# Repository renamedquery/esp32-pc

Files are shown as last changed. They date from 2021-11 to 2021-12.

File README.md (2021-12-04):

# esp32-pc

### This repo is currently a work in progress. I am currently working on the ESP32's command line.

https://user-images.githubusercontent.com/38505228/144671347-8b8e3e65-b26e-4b90-b4b4-f55994bb42a4.mp4

*Yes, it does run Bad Apple! (Make sure to run `net stop` before using `readimgseq`). A some recent updates have sped up the playback speed monumentally, and the device is now capable of ~16fps playback!*



*Currently, the master device will now allow up to 8 slave devices to sync to it over WiFi. It can also read from an SD card filesystem.*



*One of the latest updates included the ability to take screenshots. The screenshot algorithm will be improved later to use run length encoding, which should speed it up significantly.*



*I call it, "The Signal Integrity House of Horrors".*

### Specs:

- 520KB RAM
- 448KB ROM
- 240MHz processor clock speed
- 3 bit VGA colors (RGB)
- 640x350 output resolution
- 6 physical ESP32 devices

### Parts:

- 6x ESP32-S2 Dev Kit
- 1x Digital PmodSD

### Commands:

- fbmem
- fbinfo
- hwinfo
- lsdev
- net <command_args>
- df
- sd <command_args>
- mkdir <absolute_path>
- ls
- touch <absolute_path>
- cd <absolute_path>
- readimgseq <absolute_path>
- cls
- screenshot <absolute_path>

*Use the `help` command to list all of the commands and their usage. You can comment out text by writing `nop <string>`.*

### Why am I doing this?

I have quite a bit of experience programming on high end desktop computers, and thought that it would be useful to learn how to program on a system with much tighter tolerances and lower specs.

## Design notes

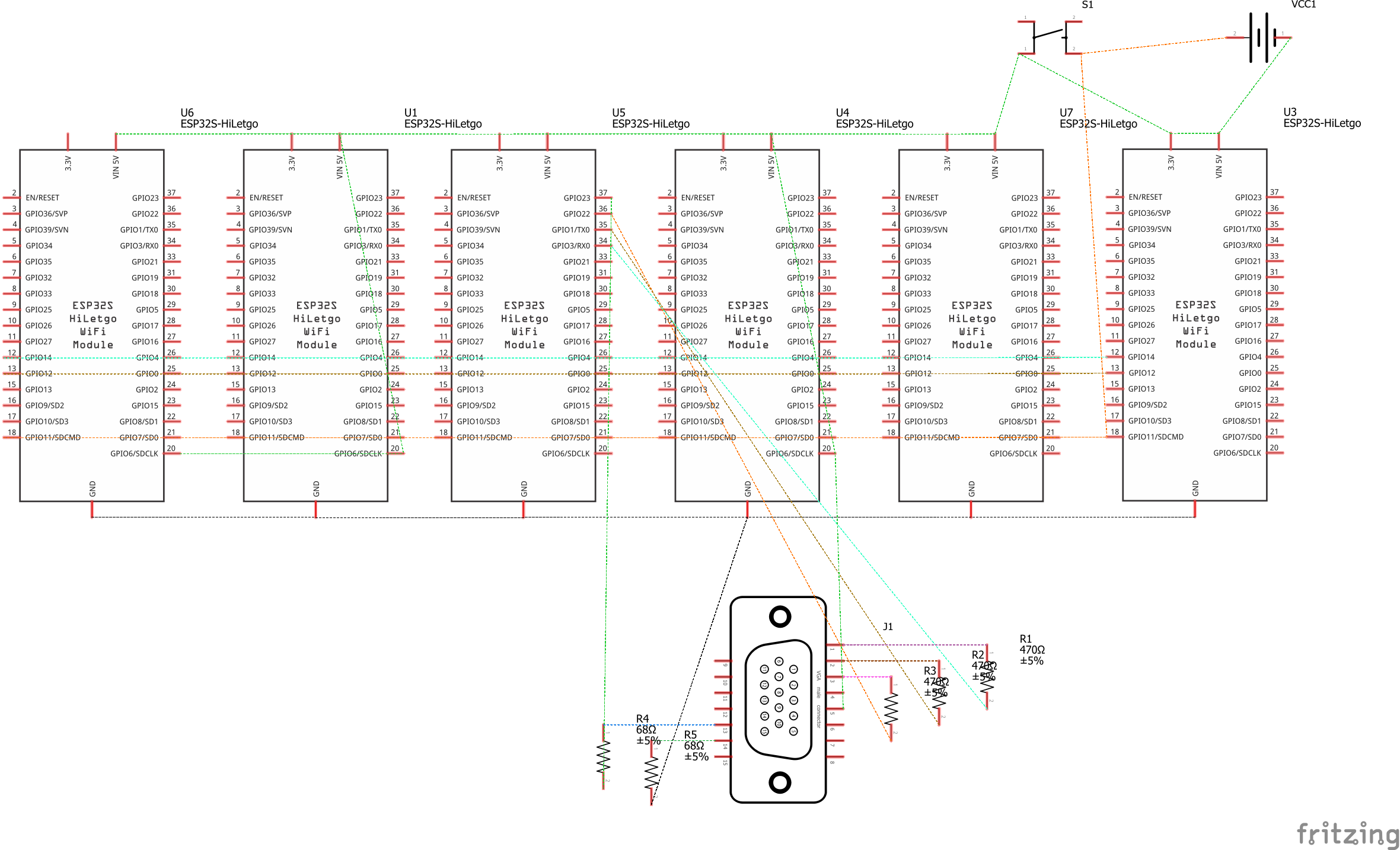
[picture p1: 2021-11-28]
schematics/esp32-computer-mockup-1_schem.png

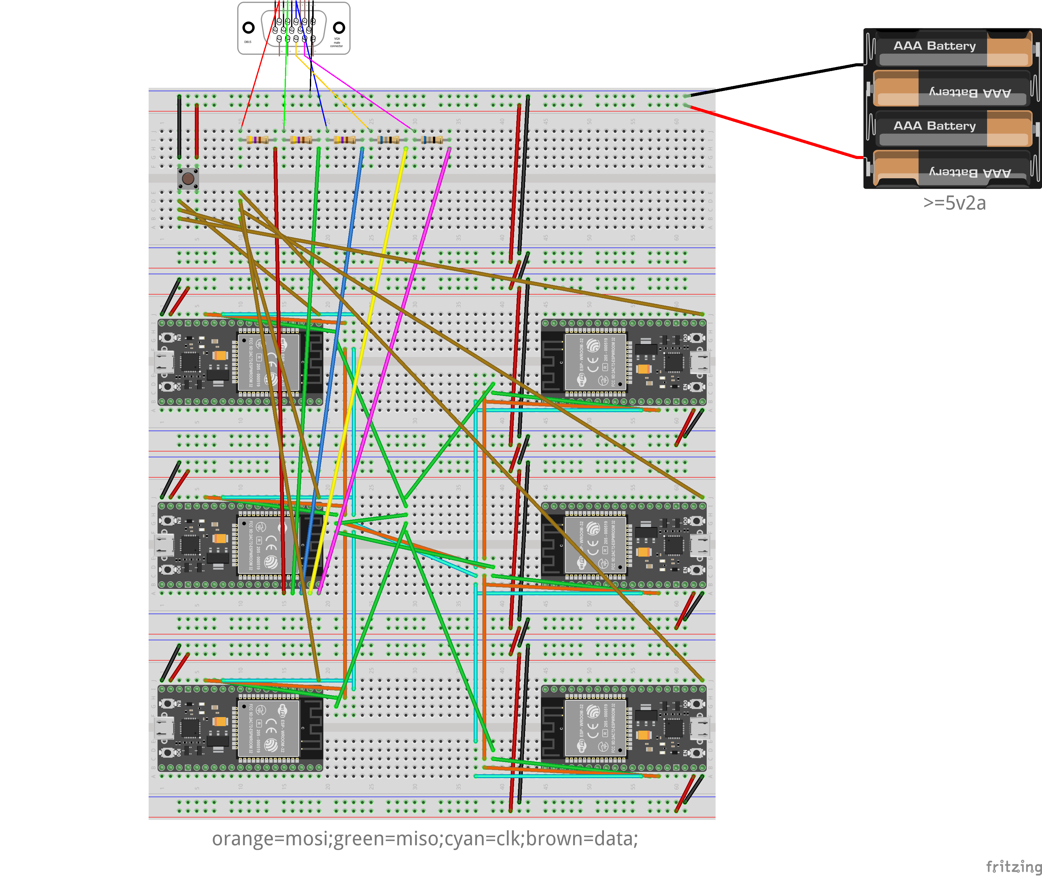
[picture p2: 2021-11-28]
schematics/esp32-computer-mockup-1_bb.png

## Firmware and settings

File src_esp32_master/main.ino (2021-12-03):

#define CONFIG_IDF_TARGET_ESP32 1

#include "cli.hpp"

void setup() {

    spi = new SPIClass(VSPI);
    spi->begin(SD_SCLK, SD_MISO, SD_MOSI, SD_SS);
    spi->setFrequency((uint32_t)(get_clock_speed_cpu_mhz()) * 1000 * 1000); // might be unstable at 240Mhz?

    WiFi.mode(WIFI_AP);
    bool softap_start_status = WiFi.softAP(WIFI_NAME, WIFI_PASSWORD, 1, 0, AP_MAX_CONNECTIONS);

    Serial.begin(9600);

    bool sd_start_status = SD.begin(SD_SS, *spi);

    vga.init(vga.MODE640x350, PIN_R, PIN_G, PIN_B, PIN_HSYNC, PIN_VSYNC);
    vga.setFont(CodePage437_9x16);
    vga.setTextColor(vga.RGB(255, 255, 255), vga.RGB(0, 0, 0));
    vga.setFrameBufferCount(2);
    vga.clear();

    char pin_info[MAX_CLI_OUTPUT_LENGTH_PER_LINE] = "";
    sprintf(pin_info, "PIN_R=%d\nPIN_G=%d\nPIN_B=%d\nPIN_HSYNC=%d\nPIN_VSYNC=%d", PIN_R, PIN_G, PIN_B, PIN_HSYNC, PIN_VSYNC);

    char clock_speed[MAX_CLI_OUTPUT_LENGTH_PER_LINE] = "";
    sprintf(clock_speed, "%dMHz CLOCK SPEED", get_clock_speed_cpu_mhz());

    char softap_start_info[MAX_CLI_OUTPUT_LENGTH_PER_LINE] = "";
    sprintf(softap_start_info, "SOFTAP STATUS %d", (byte)softap_start_status);

    char sd_start_info[MAX_CLI_OUTPUT_LENGTH_PER_LINE] = "";
    sprintf(sd_start_info, "SD STATUS %d", (byte)sd_start_status);

    pinMode(SLAVE_RESET_PIN, OUTPUT);
    digitalWrite(SLAVE_RESET_PIN, HIGH);

    vga.println("ESP-32S DEVELOPMENT BOARD");
    vga.println("520KB RAM BUILT IN/0KB EXTERNAL");
    vga.println(clock_speed);
    vga.println("640X350 PIXELS TOTAL");
    vga.println("3 BIT VGA");
    vga.println(softap_start_info);
    vga.println(pin_info);
    vga.println(sd_start_info);

    vga.println("USING ESP32LIB VGA DRIVER WRITTEN BY BITLUNI");
    vga.println("MAIN PROGRAM WRITTEN BY KATZNBOYZ");
    vga.print("REPORT ISSUES TO ");
    vga.setTextColor(vga.RGB(0, 0, 255), vga.RGB(0, 0, 0));
    vga.println("https://github.com/katznboyz1/esp32-pc");
    vga.setTextColor(vga.RGB(255, 255, 255), vga.RGB(0, 0, 0));

    vga.setTextColor(vga.RGB(255, 0, 0), vga.RGB(0, 0, 0));
    vga.println("RED COLOR TEST");
    vga.setTextColor(vga.RGB(0, 255, 0), vga.RGB(0, 0, 0));
    vga.println("GREEN COLOR TEST");
    vga.setTextColor(vga.RGB(0, 0, 255), vga.RGB(0, 0, 0));
    vga.println("BLUE COLOR TEST");
    vga.setTextColor(vga.RGB(255, 255, 255), vga.RGB(0, 0, 0));

    unsigned long boot_to_current_time = (millis() - boot_start_time);
    char boot_time_info[MAX_CLI_INPUT_LENGTH] = "";
    sprintf(boot_time_info, "BOOTING TOOK %luMS", boot_to_current_time);
    
    vga.println(boot_time_info);

    vga.println("DONE BOOTING");

    vga.println(line_separator);

    Serial.println("SETUP IS DONE");
}

void loop() {

    uint64_t current_time_ms = millis();

    while (Serial.available()) {

        String serial_string = Serial.readString();
        serial_string.replace('\n', ' ');

        char serial_string_char[MAX_CLI_INPUT_LENGTH];
        serial_string.substring(0, MAX_CLI_INPUT_LENGTH - 1).toCharArray(serial_string_char, serial_string.length() + 1);

        vga.print(">");
        vga.print(serial_string_char);
        vga.print("\n");
        scroll_terminal(1);

        if (serial_string.substring(0, 5).equals("fbmem")) {cli_output(&cli_cmd_fbmem, serial_string_char, vga);}
        else if (serial_string.substring(0, 6).equals("fbinfo")) {cli_output(&cli_cmd_fbinfo, serial_string_char, vga);} 
        else if (serial_string.substring(0, 6).equals("hwinfo")) {cli_output(&cli_cmd_hwinfo, serial_string_char, vga);} 
        else if (serial_string.substring(0, 5).equals("lsdev")) {cli_output(&cli_cmd_lsdev, serial_string_char, vga);} 
        else if (serial_string.substring(0, 3).equals("net")) {cli_output(&cli_cmd_serial, serial_string_char, vga);} 
        else if (serial_string.substring(0, 3).equals("cls")) {cli_output(&cli_cmd_cls, serial_string_char, vga);} 
        else if (serial_string.substring(0, 2).equals("df")) {cli_output(&cli_cmd_df, serial_string_char, vga);} 
        else if (serial_string.substring(0, 2).equals("sd")) {cli_output(&cli_cmd_sd, serial_string_char, vga);} 
        else if (serial_string.substring(0, 2).equals("ls")) {cli_output(&cli_cmd_ls, serial_string_char, vga);} 
        else if (serial_string.substring(0, 2).equals("cd")) {cli_output(&cli_cmd_cd, serial_string_char, vga);} 
        else if (serial_string.substring(0, 5).equals("mkdir")) {cli_output(&cli_cmd_mkdir, serial_string_char, vga);}
        else if (serial_string.substring(0, 5).equals("touch")) {cli_output(&cli_cmd_touch, serial_string_char, vga);} 
        else if (serial_string.substring(0, 10).equals("readimgseq")) {cli_output(&cli_cmd_read_image_sequence, serial_string_char, vga);} 
        else if (serial_string.substring(0, 10).equals("screenshot")) {cli_output(&cli_cmd_screenshot, serial_string_char, vga);} 
        else if (serial_string.substring(0, 4).equals("help")) {cli_output(&cli_cmd_help, serial_string_char, vga);} 
        else if (serial_string.substring(0, 3).equals("nop")) {cli_output(&cli_cmd_nop, serial_string_char, vga);} 
        else if (serial_string.substring(0, 3).equals("err")) {cli_output(&cli_cmd_err, serial_string_char, vga);} 
        else if (serial_string.substring(0, 6).equals("reboot")) {reset();} 
        else {cli_nocmd();}
    }

    if (!image_dir_in_queue.isEmpty() && !kill_current_async_task) {

        image_last_draw_time_ms = current_time_ms;

        try {

            String current_img = String(last_image_frame);
            char current_img_char[10] = "";
            current_img.toCharArray(current_img_char, 10);

            sprintf(current_img_char, "%09d", last_image_frame);

            current_img = String(current_img_char) + ".jpg.esp32binimg";

            File image_to_draw = SD.open(image_dir_in_queue + '/' + current_img, "rb");

            // we will miss some data, but thats okay
            image_to_draw.setTimeout(time_between_image_frame_draw_ms / 2);

            //String current_img_res = image_to_draw.readStringUntil('\n');

            int image_width, image_height, image_width_rescaled, image_height_rescaled;

            // tempoary values just to test things out
            // TODO: fix this
            image_height = 80 * 2; //current_img_res.substring(0, current_img_res.indexOf(";")).toInt();
            image_width = 60 * 2; //current_img_res.substring(current_img_res.indexOf(";"), current_img_res.length()).toInt();

            const int image_scale = 2;

            int x_aspect = (SCREEN_WIDTH / image_width / image_scale) * 1.5;
            int y_aspect = SCREEN_HEIGHT / image_height / image_scale;

            int x = 0;
            int y = 0;

            int anchor_x = 0;
            int anchor_y = 0;

            int current_embedded_frame = 0;

            while (image_to_draw.available() > 0) {

                byte current_pix_value_str = image_to_draw.read();
                byte current_pix_run_length = image_to_draw.read();

                bool current_pix_val_1bit = !((bool)(current_pix_value_str));

                unsigned char pix_clr = vga.RGB(current_pix_val_1bit * 255, current_pix_val_1bit * 255, current_pix_val_1bit * 255);

                for (int i = 0; i < current_pix_run_length; i++) {

                    if (x >= image_width) {

                        y++;
                        x = 0;
                    }

                    if (y >= image_height) {

                        y = 0;
                        x = 0;
                        current_embedded_frame++;
                    }

                    if (vga.frameBuffers[vga.currentFrameBuffer][y][x] != pix_clr) vga.fillRect(((x) * x_aspect) + anchor_x, ((y * 2) * y_aspect) + anchor_y, x_aspect, (y_aspect * 2), pix_clr);

                    x++;
                }

                x++;
            }

            image_to_draw.close();

            last_image_frame++;

        } catch (...) {

            image_dir_in_queue = "";
        }
    }

    loop_index++;
}

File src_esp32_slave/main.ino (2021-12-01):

#define WIFI_NAME "ESP32_MASTER_COMPUTE_DEVICE_1"
#define WIFI_PASSWORD "YOUR PASSWORD GOES HERE"
#define LED_PIN_RED 27
#define LED_PIN_GREEN 26

#include <WiFi.h>

void setup() {
    
    Serial.begin(9600);

    WiFi.mode(WIFI_STA);
    WiFi.disconnect();

    delay(100);

    WiFi.begin(WIFI_NAME, WIFI_PASSWORD);

    long long int current_time = millis();
    long long int max_allowed_wait_time_ms = 10 * 1000; // 10s

    pinMode(LED_PIN_RED, OUTPUT);
    pinMode(LED_PIN_GREEN, OUTPUT);

    digitalWrite(LED_PIN_RED, HIGH);
    digitalWrite(LED_PIN_GREEN, LOW);

    while (WiFi.status() != WL_CONNECTED) {

        delay(10*5);

        auto wifi_status = WiFi.status();

        if (wifi_status == WL_NO_SSID_AVAIL || wifi_status == WL_CONNECT_FAILED || wifi_status == WL_CONNECTION_LOST || millis() >= max_allowed_wait_time_ms) {

            Serial.println(wifi_status);

            break;
        }
    }

    if (WiFi.status() == WL_CONNECTED) {
 
        digitalWrite(LED_PIN_GREEN, HIGH);

        delay(10*30);
    }

    digitalWrite(LED_PIN_RED, LOW);
    digitalWrite(LED_PIN_GREEN, LOW);
}

void loop() {

    digitalWrite(LED_PIN_RED, LOW);
}

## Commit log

2021-11-27 added esp32 binaries
2021-11-28 began working on the main arduino file
2021-11-28 switched _PINS.G and _PINS.R
2021-11-28 switching variables with definitions
2021-11-28 updated the schematics
    [esp32-computer-mockup-1.fzz]
2021-11-28 changed esp32-xxx to src_esp32_xxx
2021-11-28 vga was plugged into a slave device, switched it to master
    [esp32-computer-mockup-1.fzz]
2021-11-28 added a power source to the schematic
    [esp32-computer-mockup-1.fzz]
2021-11-28 calibration grid
2021-11-28 changed the frame counter layout, and made its clear rate half of the refresh rate
2021-11-29 somewhat got the boolean framebuffer to work
2021-11-29 used a temporary hack to get the framebuffer to use 1 bit integers instead of 8 bit integers
2021-11-29 indicated the size of the framebuffer
2021-11-29 fixed the spacing of text on the screen
    [main.ino]
2021-11-29 reduced the output size to 104x35 to get the framebuffer size under 1kb
2021-11-29 linked github.com/bitluni/ESP32Lib
2021-11-29 changed colors/fixed blackout issues by removing the g/b pins
    [main.ino]
2021-11-29 added esp32lib
2021-11-29 retrying to include esp32lib
2021-11-29 fixed the spacing for the console input
    [main.ino]
2021-11-29 typing a newline char over serial no longer breaks the terminal
    [main.ino]
2021-11-30 fixed a scrolling issue with fbinfo
    [main.ino]
2021-11-30 made a hacky reboot function
    [main.ino]
2021-11-30 added a lsdev command to list the slave devices
2021-11-30 added a command that throws an error (for testing)
    [main.ino]
2021-11-30 fixed an issue with scroll_terminal() not scrolling far enough in cli_cmd_help()
    [main.ino]
2021-11-30 added the beginning of the spi interface
2021-11-30 added spi to the help menu
2021-11-30 trying to get spi to work
2021-11-30 halfway through getting spi to work
2021-11-30 spi doesnt crash the device anymore, it doesnt work though
    [main.ino]
2021-11-30 spi wont work, using softwareserial instead
2021-11-30 debugging the serial issue
    [main.ino]
2021-11-30 still debugging the serial issue
    [main.ino]
2021-12-01 fixed a scrolling issue on GNU bash, version 5.0.17(1)-release (x86_64-pc-linux-gnu) These shell commands are defined internally. Type `help' to see this list. Type `help name' to find out more about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
    A star (*) next to a name means that the command is disabled.
    job_spec [&] history [-c] [-d offset] [n] or history -anrw [filename] or history -ps arg [arg...]
    (( expression ))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
    [main.ino]
2021-12-01 wrong commit message, meant to say that I fixed the help command
    [main.ino]
2021-12-01 minor fixes to the wifi commands
    [main.ino]
2021-12-01 fixed the spacing on the net help output
    [main.ino]
2021-12-01 fixed the var for the softap start info
    [main.ino]
2021-12-01 added a (broken) 'df' command - will fix later
    [main.ino]
2021-12-01 added a command to restart the slave devices
2021-12-01 fixed spacing for lsdev/net list
    [main.ino]
2021-12-01 fixed spacing for the help commands output
    [main.ino]
2021-12-01 fixed an issue with sprintf in cli_cmd_mkdir
    [main.ino]
2021-12-01 writing to an existing file wont crash the os
    [main.ino]
2021-12-01 added a known issue
    [main.ino]
2021-12-01 added another known touch issue
    [main.ino]
2021-12-02 trying to fix guru mediation errors
    [main.ino]
2021-12-02 Revert "got auto-scaling working"
    This reverts commit d3948fd41f7437d94a8409b73f0aece2dd25a80f.
    [main.ino]
2021-12-02 removed frame clock timer
2021-12-02 cut the image filesize in half by writing binary instead of text
2021-12-02 changed the file extension to .esp32binimg
2021-12-02 maxed out the spi frequency
2021-12-02 equal pixels are no longer overwritten
    [main.ino]
2021-12-03 upon boot, the screen clears before printing anything
2021-12-03 tried to implement rle - it failed - reverting
    [main.ino]
2021-12-03 forcefully reverted to 9e1f271e16660b3792b79a94b91f3cc114824230
    [main.ino]
2021-12-03 sped up the image read speed by n(x) by encasing multiple frames in one file
2021-12-03 improved performance in longer videos by setting the video frames per file to 16
2021-12-03 uploading frame rate changes for rgb2bw.py
